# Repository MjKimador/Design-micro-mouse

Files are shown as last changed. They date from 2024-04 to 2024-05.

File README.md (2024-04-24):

This project includes two subsystems.
The power subsytem has files named with the suffix Power.
The sensing subsystems has files named with suffix Sensing.
There are two branches through which changes are made and the main branch holds files for both sensing subsystem and power subsystem.

For the Power Subsystem:
This system has been designed to provide power to the micro mouse system. It is designed using kiCad and to open the file you can open the .pro file and you will haev the entire project including the pcb files and schematic. The files used for ordering which inlude BOM files and all other files are not included in this folder but the project has all fields filled makingh it possible for all required files to be opened with ease.

For the Sensing Subsystem:
The subsystem serves as the sensory "eyes" of the micromouse, detecting obstacles in its path and facilitating navigation. It integrates easily with other features, ensuring efficient power usage and reliable obstacle detection within budgetary constraints.The design was done using kicad .The documents included are pcb ,schenatic and datasheet of components used.

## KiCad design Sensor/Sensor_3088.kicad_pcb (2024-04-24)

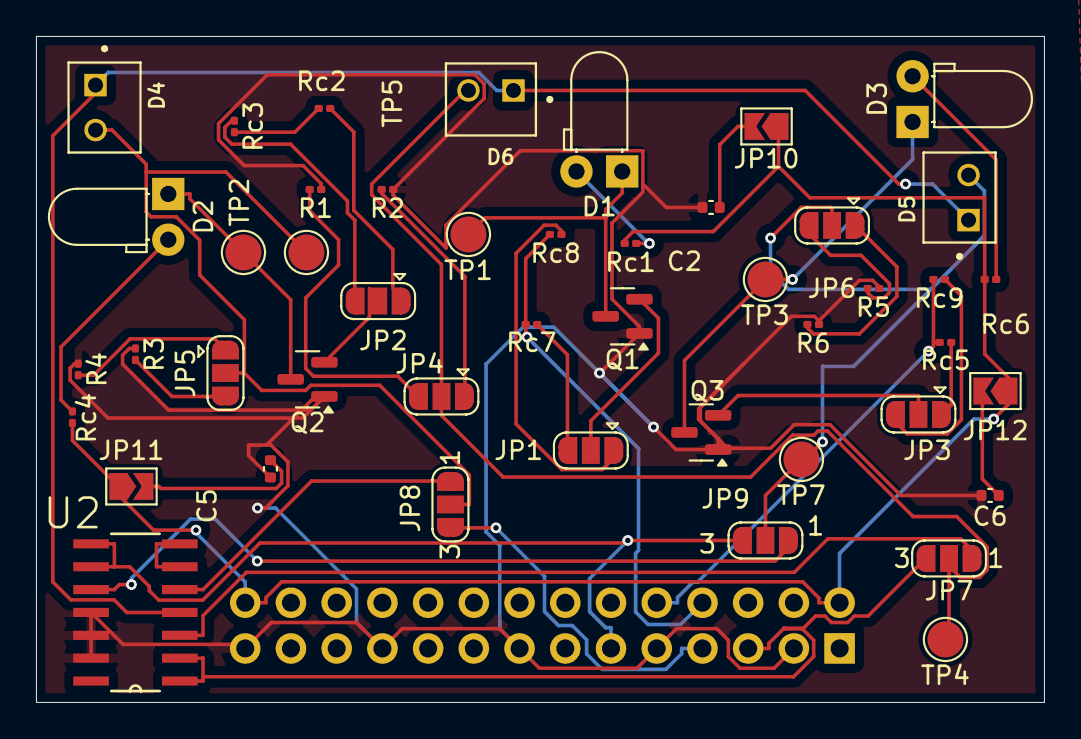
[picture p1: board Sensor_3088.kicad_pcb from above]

Board: 2 copper layers, 56.0 x 37.0 mm, 47 parts (1 on the bottom side), 40 nets.

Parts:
C2, C5, C6: 10n; C_0402_1005Metric
D1, D2, D3: TSAL4400; LED_D3.0mm_Horizontal_O1.27mm_Z2.0mm_IRBlack
D4, D5, D6: BPW41N; DIO_BPW41N
J2: Conn_02x14_Odd_Even; PinHeader_2x14_P2.54mm_Vertical
JP1, JP2, JP3, JP4, JP5, JP6: SolderJumper_3_Open; SolderJumper-3_P1.3mm_Open_RoundedPad1.0x1.5mm
JP7, JP8, JP9: SolderJumper_3_Open; SolderJumper-3_P1.3mm_Open_RoundedPad1.0x1.5mm_NumberLabels
JP10, JP11, JP12: SolderJumper_2_Open; SolderJumper-2_P1.3mm_Open_TrianglePad1.0x1.5mm
Q1, Q2, Q3: SS8050; SOT-23
R1, R3, R5: 10k; R_0201_0603Metric
R2, R4, R6: 150k; R_0201_0603Metric
Rc1, Rc4, Rc6: 20; R_0201_0603Metric
Rc2, Rc5, Rc8: 1k; R_0201_0603Metric
Rc3, Rc7, Rc9: 470; R_0201_0603Metric
TP1, TP2, TP3, TP4, TP5, TP7: TestPoint; TestPoint_Pad_D2.0mm
U2: LM324DT; SOIC127P600X175-14N

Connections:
3V3: J2.2, J2.28, JP10.1 (A), JP11.1 (A), JP12.1 (A), Rc1.2, Rc4.2, Rc6.2
+3V3: D4.C, D5.C, D6.C, U2.4 (VCC+)
GND: C2.2, C5.2, C6.2, J2.3, J2.9, J2.15, J2.21, J2.27, Q1.1 (E), Q2.1 (E), Q3.1 (E), R1.1, R2.1, R3.1, R4.1, R5.1, R6.1, U2.11 (VCC-), U2.12 (POS_4), U2.13 (NEG_4)
unnamed: D1.2 (A), Rc1.1
unnamed: D1.1 (K), Q1.3 (C), TP1.1
unnamed: D2.2 (A), Rc4.1
unnamed: D2.1 (K), Q2.3 (C), TP2.1
unnamed: D3.2 (A), Rc6.1
unnamed: D3.1 (K), Q3.3 (C), TP3.1
unnamed: JP1.1 (A), Rc8.1
unnamed: JP1.3 (B), Rc7.1
unnamed: JP1.2 (C), Q1.2 (B)
unnamed: JP2.1 (A), Rc2.1
unnamed: JP2.3 (B), Rc3.1
unnamed: JP2.2 (C), Q2.2 (B)
unnamed: JP3.1 (A), Rc5.1
unnamed: JP3.3 (B), Rc9.1
unnamed: JP3.2 (C), Q3.2 (B)
unnamed: JP4.1 (A), R2.2
unnamed: JP4.3 (B), R1.2
unnamed: JP5.1 (A), R4.2
unnamed: JP5.3 (B), R3.2
unnamed: JP6.1 (A), R6.2
unnamed: JP6.3 (B), R5.2
unnamed: C2.1, JP10.2 (B)
unnamed: C5.1, JP11.2 (B)
unnamed: C6.1, JP12.2 (B)
unnamed: U2.6 (NEG_2), U2.7 (OUT2)
OUT1: D6.A, JP4.2 (C), JP7.2 (C), TP4.1
Output2: D4.A, JP5.2 (C), JP8.2 (C), TP5.1
Output3: D5.A, JP6.2 (C), JP9.2 (C), TP7.1
PA3: J2.5, JP7.3 (B), U2.1 (OUT1), U2.2 (NEG_1)
PA4: J2.7, JP8.3 (B)
PA5: J2.11, JP9.3 (B), U2.8 (OUT3), U2.9 (NEG3)
PE13: Rc2.2, Rc3.2
PE14: J2.10, Rc5.2, Rc9.2
PE15: J2.8, Rc7.2, Rc8.2
POS1: JP7.1 (A), U2.3 (POS_1)
POS2: JP8.1 (A), U2.5 (POS_2)
POS3: JP9.1 (A), U2.10 (POS_3)

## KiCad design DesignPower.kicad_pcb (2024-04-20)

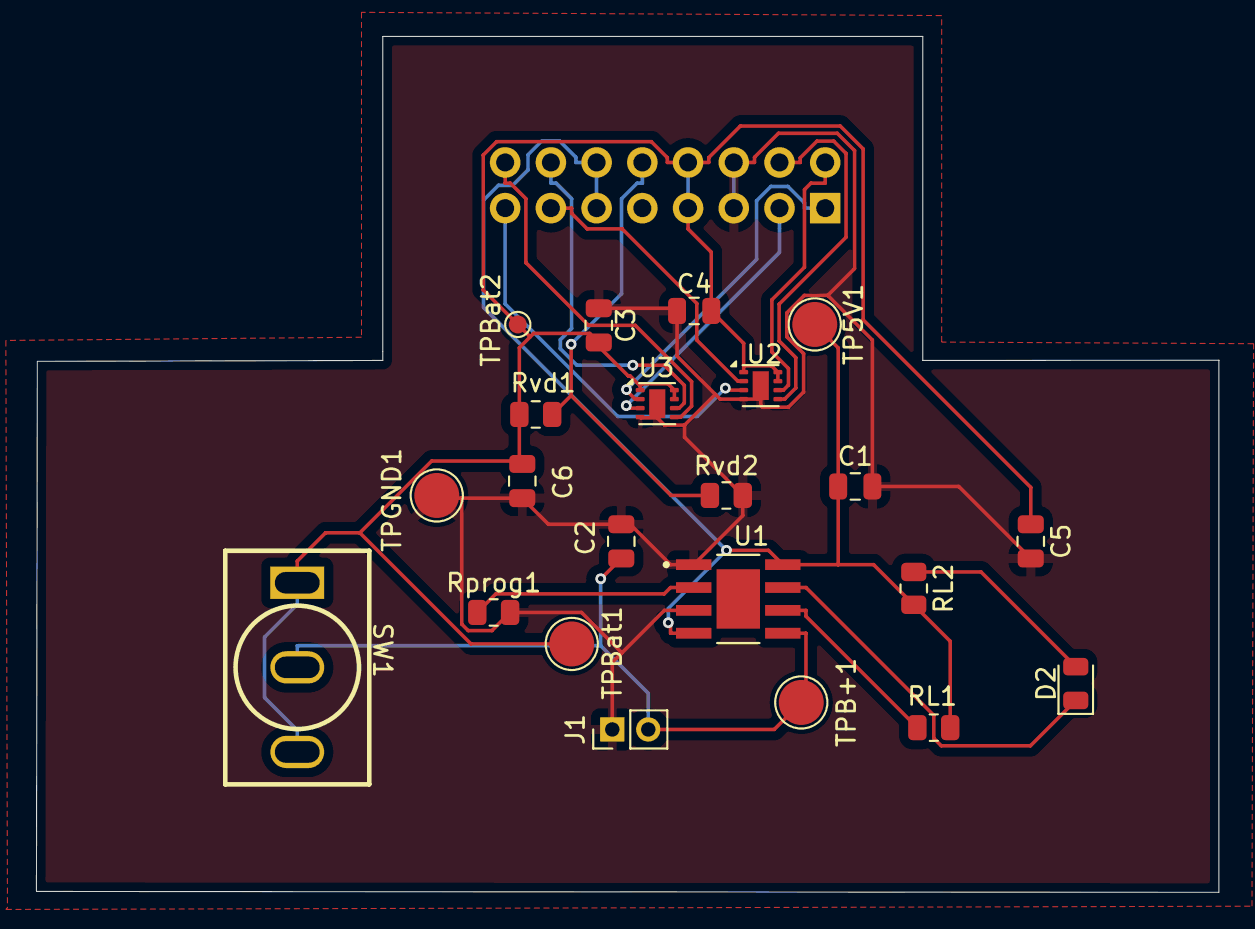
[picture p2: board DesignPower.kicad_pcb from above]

Board: 2 copper layers, 65.7 x 47.6 mm, 23 parts (1 on the bottom side), 17 nets.

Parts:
C1, C2: 10uf; C_0805_2012Metric
C3, C4, C5, C6: 100nF; C_0805_2012Metric
D2: LED; LED_0805_2012Metric
J1: Conn_01x02_Pin; PinHeader_1x02_P2.00mm_Vertical
J2: Conn_02x08_Odd_Even; PinHeader_2x08_P2.54mm_Vertical
RL1, RL2: 1000; R_0805_2012Metric
Rprog1: 6800; R_0805_2012Metric
Rvd1: 200k; R_0805_2012Metric
Rvd2: 510k; R_0805_2012Metric
SW1: SW-TH_MT-0-103-A101-M200-RS
TP5V1: 5V-bat test; TestPoint_Pad_D2.5mm
TPB+1: TestPoint; TestPoint_Pad_D2.5mm
TPBat1: TestPoint; TestPoint_Pad_D2.5mm
TPBat2: BATT; TestPoint_Pad_D1.0mm
TPGND1: TestPoint; TestPoint_Pad_D2.5mm
U1: TP4056; SOIC127P600X175-9N
U2, U3: DRV8837; WSON-8-1EP_2x2mm_P0.5mm_EP0.9x1.6mm

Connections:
+5V: C1.1, J2.11, J2.12, RL1.2, RL2.2, TP5V1.1, U1.4 (VCC), U1.8 (CE)
/B+: C2.2, J1.2, SW1.2, TPB+1.1, U1.5 (BAT)
BATT: C3.1, C4.1, C5.1, C6.1, J2.7, J2.8, Rvd1.1, SW1.1, SW1.3, TPBat1.1, TPBat2.1, U2.1 (VM), U2.7 (~SLEEP), U2.8 (VCC), U3.1 (VM), U3.7 (~SLEEP), U3.8 (VCC)
BATT_ADC: J2.10, Rvd1.2, Rvd2.1
GND: C1.2, C2.1, C3.2, C4.2, C5.2, C6.2, J1.1, J2.5, J2.6, Rprog1.2, Rvd2.2, TPGND1.1, U1.1 (TEMP), U1.3 (GND), U2.4 (GND), U2.9 (GND), U3.4 (GND), U3.9 (GND)
Motor1_A: J2.13, U2.2 (OUT1)
Motor1_B: J2.15, U2.3 (OUT2)
Motor2_A: J2.1, U3.2 (OUT1)
Motor2_B: J2.3, U3.3 (OUT2)
unnamed: D2.2 (A), RL2.1
unnamed: D2.1 (K), U1.7 (*CHRG)
unnamed: RL1.1, U1.6 (*STDBY)
unnamed: Rprog1.1, U1.2 (PROG)
PWM1: J2.2, U2.6 (IN1)
PWM2: J2.4, U2.5 (IN2)
PWM3: J2.14, U3.6 (IN1)
PWM4: J2.16, U3.5 (IN2)

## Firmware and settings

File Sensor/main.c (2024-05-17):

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
/* Includes ------------------------------------------------------------------*/
#include "main.h"
#include "adc.h"
#include "gpio.h"
#include <lcd_stm32f0.c>


/* USER CODE BEGIN PV */
//JUSTIN - START 1/3
uint16_t adc_value;
uint16_t adc_value1;
uint16_t adc_value2;
uint8_t channel = 0;
//JUSTIN - END
/* USER CODE END PV */

void SystemClock_Config(void);
/**
  * @brief  The application entry point.
  * @retval int
  */
int main(void)
{

  /* MCU Configuration--------------------------------------------------------*/

  /* Reset of all peripherals, Initializes the Flash interface and the Systick. */
  HAL_Init();

  /* Configure the system clock */
  SystemClock_Config();

  /* Initialize all configured peripherals */
  MX_GPIO_Init();
  MX_ADC_Init();
  init_LCD();
  /* Infinite loop */
  /* USER CODE BEGIN WHILE */
  while (1)
  {
    /* USER CODE END WHILE */

    /* USER CODE BEGIN 3 */
    //JUSTIN - START 2/3
   ADC1-> CHSELR= ADC_CHSELR_CHSEL0;
    HAL_Delay(10);
    HAL_ADC_Start(&hadc);
    HAL_GPIO_WritePin(LED7_GPIO_Port,LED7_Pin,RESET);
    while(HAL_ADC_PollForConversion(&hadc,5)!= HAL_OK);
    adc_value = HAL_ADC_GetValue(&hadc);
    if(adc_value<2200) {
      HAL_GPIO_WritePin(LED7_GPIO_Port,LED7_Pin,SET);
    } else {
      HAL_GPIO_WritePin(LED7_GPIO_Port,LED7_Pin,RESET);
    }
    HAL_ADC_Stop(&hadc);
    



    ADC1->CHSELR=ADC_CHSELR_CHSEL1;
    HAL_Delay(10);
    HAL_ADC_Start(&hadc);
    HAL_GPIO_WritePin(LED6_GPIO_Port,LED6_Pin,RESET);
    while(HAL_ADC_PollForConversion(&hadc,5)!= HAL_OK);
    adc_value1 = HAL_ADC_GetValue(&hadc);
    if(adc_value1<1900) {
      HAL_GPIO_WritePin(LED6_GPIO_Port,LED6_Pin,SET);
    } else {
      HAL_GPIO_WritePin(LED6_GPIO_Port,LED6_Pin,RESET);
    }
    HAL_ADC_Stop(&hadc);



   ADC1->CHSELR=ADC_CHSELR_CHSEL2;
    HAL_Delay(10);
    HAL_ADC_Start(&hadc);
    HAL_GPIO_WritePin(LED5_GPIO_Port,LED5_Pin,RESET);
    while(HAL_ADC_PollForConversion(&hadc,5)!= HAL_OK);
    adc_value2 = HAL_ADC_GetValue(&hadc);
    if(adc_value2<2000) {
      HAL_GPIO_WritePin(LED5_GPIO_Port,LED5_Pin,SET);
    } else {
      HAL_GPIO_WritePin(LED5_GPIO_Port,LED5_Pin,RESET);
    }
    HAL_ADC_Stop(&hadc);
    lcd_command(CLEAR);
   char str[50]; // Assuming a sufficient buffer size for the resulting string
char str2[12];
char str_adc_value[10]; // Assuming a sufficient buffer size for the ADC value
char str_adc_value1[10]; // Assuming a sufficient buffer size for the ADC value
char str_adc_value2[10]; // Assuming a sufficient buffer size for the ADC value

// Convert numerical values to strings
sprintf(str_adc_value, "%d", adc_value);
sprintf(str_adc_value1, "%d", adc_value1);
sprintf(str_adc_value2, "%d", adc_value2);

// Concatenate strings and pass them to lcd_putstring
lcd_putstring("LO:");
lcd_putstring(str_adc_value);
lcd_putstring(" MO:");
lcd_putstring(str_adc_value1);
lcd_command(LINE_TWO);
lcd_putstring("RO:");
lcd_putstring(str_adc_value2);

  



    //JUSTIN - END
  }
  /* USER CODE END 3 */
}

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
/* USER CODE BEGIN 4 */
//JUSTIN - START 3/3
/* I took this code from the adc.c file - In the init section.
* Regrettably setting up the ADC for reading multiple channels is not great without using DMA (scary)
* So you would need to just look at that file and work out how to modify your set channel accordingly.
*/
void adc_set_channel(uint8_t num) {
    ADC_ChannelConfTypeDef sConfig = {0};

    if (num>0) {
      sConfig.Channel = ADC_CHANNEL_5;
    } else {
      sConfig.Channel = ADC_CHANNEL_6;
    }
    sConfig.Rank = ADC_RANK_CHANNEL_NUMBER;
    sConfig.SamplingTime = ADC_SAMPLETIME_1CYCLE_5;
    if (HAL_ADC_ConfigChannel(&hadc, &sConfig) != HAL_OK)
    {
      Error_Handler();
    }
}
//JUSTIN - END
/* USER CODE END 4 */
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


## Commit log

2024-04-20 Added a new motor driver
2024-04-24 Add files via upload
    sensor subsystem files.
    [Sensor_3088.kicad_pcb, Sensor_3088.kicad_sch]
2024-04-24 Update README.md
    Added information on sensor subsystem

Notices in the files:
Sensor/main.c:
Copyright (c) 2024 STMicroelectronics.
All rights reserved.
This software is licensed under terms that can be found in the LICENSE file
